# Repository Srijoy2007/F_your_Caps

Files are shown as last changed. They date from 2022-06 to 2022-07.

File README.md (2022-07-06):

Bobby-Pad is a 9 switches budget macro-keyboard with a great quality...

#PROJECT DETAILS ->
    1. PCB :- the pcb is based of RP2040 , the pcb has the basic structure of any RP2040 PCB 
              it contains a USB C recptable support , Along with it it contains a Rotary Encoder 
	      switch and a 2.3cm OLED. 
    2. FIRMWARE :- Since RP2040 doesen't support QMK so I am builduing a custom FIRMWARE with Rust(will update it soon)
    3. CASE & PLATE :- For the Case and plate I am planning for alimunium to give it a weight , the design still under process

# ROAD MAP ->
  
  -> First commit the V1 with STM32 [ 05/22] { STM32 doesnt fit into the budget}
  -> Second change V2 with RP2040 [06/22] {Had issue with position and connections}
  -> Third change V3 with RP2040 [06/22]  { 0 errors }

#My thoughts ->
 * I built the Version 1 without knowing much about its price but when I knew that I was shocked so I switched to RP2040 which was not 
   that difficult to adapt as it has a good datasheet and guide provided in its official website , but this mcu is not much supported by 
   the keyboard community still I feel comfortable to use this one . I ordered a Raberry Pi PICO for dry run and testing the firmware code 
   before putting it to the PCBs (Might upload pics of it). 

#BUDGET -> 
 
 * PCB build + Bottom Assembly : 44$ FOR 5 PCB (i.e. Rs. 3,432) 
 * SWITCHES (Cherry MX RGB blue) : 26$ FOR 50 switches (i.e. Rs.2,025)
 * Rotary encoder + oled :  8$ - 9$  per keeb :- total 40$ - 45$ for 5 keeb
 * Case & plate : --

  #CURRENT TOTAL FOR EACH KEYBOARD (NO PLATE &  CASE) : 24$ build cost 
#TO-DO ->
 [X] PCB design
 [x] PCB Test
 [ ] Firmware test/build 
 [ ] Case and plate design 
 [ ] Final test

* All the pcb related files are uploaded

© 2022 GitHub, Inc.
Terms
Privacy
Security
Status
Docs
Contact GitHub
Pricing
API
Training
Blog
About

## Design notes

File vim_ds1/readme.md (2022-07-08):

# vim_ds1

vim_ds1

*A short description of the keyboard/project*

* Keyboard Maintainer: [Srijoy Ganguly](https://github.com/Srijoy2007)
* Hardware Supported: *The PCBs, controllers supported*
* Hardware Availability: *Links to where you can find this hardware*

Make example for this keyboard (after setting up your build environment):

   make vim_ds1:default 

Flashing example for this keyboard:

    make vim_ds1:default:flash

See the [build environment setup](https://docs.qmk.fm/#/getting_started_build_tools) and the [make instructions](https://docs.qmk.fm/#/getting_started_make_guide) for more information. Brand new to QMK? Start with our [Complete Newbs Guide](https://docs.qmk.fm/#/newbs).

## Bootloader

Enter the bootloader in 3 ways:

* **Bootmagic reset**: Hold down the key at (0,0) in the matrix (usually the top left key or Escape) and plug in the keyboard
* **Physical reset button**: Briefly press the button on the back of the PCB - some may have pads you must short instead
* **Keycode in layout**: Press the key mapped to `RESET` if it is available

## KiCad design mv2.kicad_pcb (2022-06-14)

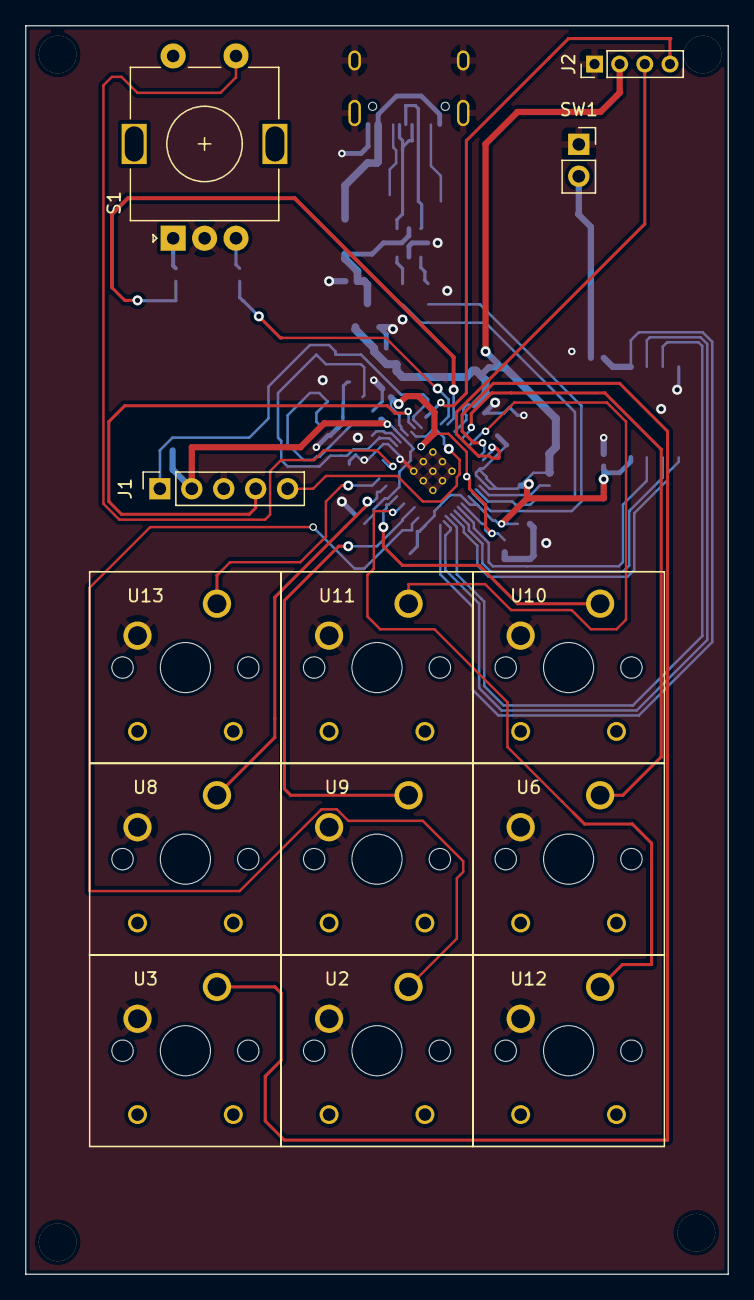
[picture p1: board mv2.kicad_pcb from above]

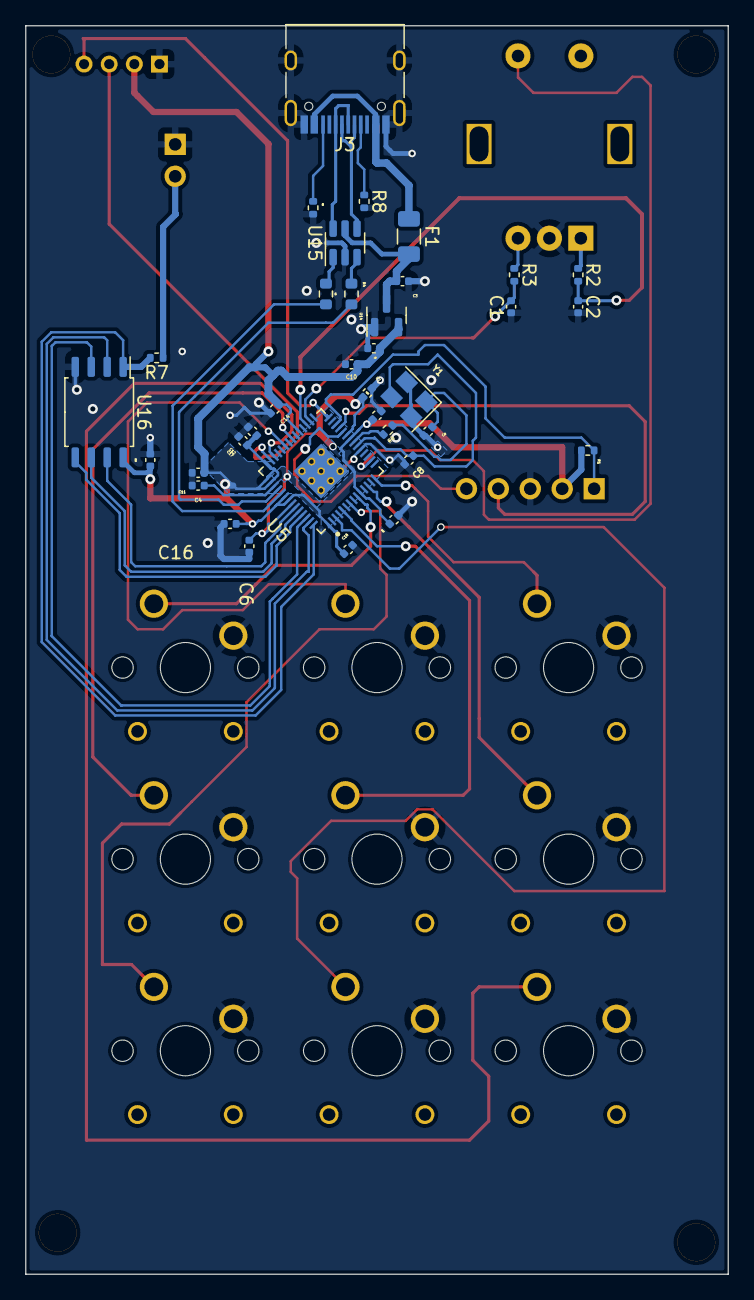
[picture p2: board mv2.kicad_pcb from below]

Board: 2 copper layers, 55.9 x 99.3 mm, 48 parts (35 on the bottom side), 42 nets.

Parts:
C1, C2, C6, C7, C12, C13, C14, C15, C16, C17, C18, C19: 100nF; C_0402_1005Metric
C3, C4, C5, C11: 1uF; C_0402_1005Metric
C8: 22pF; C_0402_1005Metric
C10: 10uF; C_0402_1005Metric
Ce: 22pF; C_0402_1005Metric
F1: 500mA; Fuse_1206_3216Metric
J1: SWD; PinSocket_1x05_P2.54mm_Vertical
J2: Conn_01x04; PinHeader_1x04_P2.00mm_Vertical
J3: USB_C_Receptacle_USB2.0; USB_C_Receptacle_HRO_TYPE-C-31-M-12
R1, R6, R7: 1k; R_0402_1005Metric
R2, R3: 27k; R_0402_1005Metric
R4, R5: 27R; R_0603_1608Metric
R8, R9: 5k1; R_0402_1005Metric
S1: ENCODER-SWITCH; RotaryEncoder_Alps_EC11E-Switch_Vertical_H20mm
SW1: SW_Push; PinSocket_1x02_P2.54mm_Vertical
U2, U3, U6, U8, U9, U10, U11, U12, U13: MX1A-11NN; CHERRY_MX1A-11NN_SWITCH
U5: RP2040; QFN40P700X700X90-57N
U14: XC6206PxxxMR-Regulator_Linear; SOT-23
U15: USBLC6-2SC6; SOT-23-6
U16: W25Q128JVS; SOIC-8_5.23x5.23mm_P1.27mm
Y1: 12MHz; Crystal_SMD_3225-4Pin_3.2x2.5mm

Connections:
+1V1: C4.1, C6.1, C7.1, U5.23 (DVDD), U5.45 (VREG_VOUT), U5.50 (DVDD)
+3V3: C5.2, C10.1, C11.1, C12.1, C13.1, C14.1, C15.1, C16.1, C17.1, C18.1, C19.1, J1.2, J2.2, R1.1, U5.1 (IOVDD), U5.10 (IOVDD), U5.22 (IOVDD), U5.33 (IOVDD), U5.42 (IOVDD), U5.43 (ADC_AVDD), U5.44 (VREG_VIN), U5.48 (USB_VDD), U5.49 (IOVDD), U14.2 (VO), U16.8 (VCC)
+5V: C3.2, F1.2, U14.3 (VI), U15.5 (VBUS)
/But_1: U2.P$1, U5.3 (GPIO1)
/But_2: U5.5 (GPIO3), U9.P$1
/But_3: U5.7 (GPIO5), U12.P$1
/But_4: U3.P$1, U5.40 (GPIO28/ADC2)
/But_6: U5.9 (GPIO7), U10.P$1
/But_8: U5.12 (GPIO9), U8.P$1
/But_9: U5.14 (GPIO11), U13.P$1
/But_11: U5.35 (GPIO23), U6.P$1
/But_12: U5.37 (GPIO25), U11.P$1
/CC2: J3.B5 (CC2), R9.1
/GPIO19: C1.2, R3.2, U5.30 (GPIO19)
/GPIO20: C2.1, R2.2, U5.31 (GPIO20)
/XTAL_O: Ce.2, R6.1, Y1.1
/~USB_BOOT: R7.1, SW1.2
CS: R7.2, U5.56 (QSPI_CSN), U16.1 (~CS)
D_N: R4.1, U15.3 (I/O2)
D_P: R5.1, U15.1 (I/O1)
D_USB_N: J3.A7 (D-), J3.B7 (D-), U15.4 (I/O2)
D_USB_P: J3.A6 (D+), J3.B6 (D+), U15.6 (I/O1)
GND: C1.1, C2.2, C3.1, C4.2, C5.1, C6.2, C7.2, C8.1, C10.2, C11.2, C12.2, C13.2, C14.2, C15.2, C16.2, C17.2, C18.2, C19.2, Ce.1, J1.3, J2.1, J3.A1 (GND), J3.A12 (GND), J3.B1 (GND), J3.B12 (GND), J3.S1 (SHIELD), R8.2, R9.2, S1.C, SW1.1, U2.P$2, U3.P$2, U5.19 (TESTEN), U5.57 (GND), U6.P$2, U8.P$2, U9.P$2, U10.P$2, U11.P$2, U12.P$2, U13.P$2, U14.1 (GND), U15.2 (GND), U16.4 (GND), Y1.2, Y1.4
GPI0 17: J2.4, U5.28 (GPIO17)
GPIO21: S1.S1, U5.16 (GPIO13)
GPIO 18: J2.3, U5.41 (GPIO29/ADC3)
unnamed: J3.A5 (CC1), R8.1
unnamed: R2.1, S1.A
unnamed: R3.1, S1.B
unnamed: R4.2, U5.46 (USB_DM)
unnamed: R5.2, U5.47 (USB_DP)
QSPI_CLK: U5.52 (QSPI_SCLK), U16.6 (CLK)
SD0: U5.53 (QSPI_SD0), U16.5 (DI(IO0))
SD1: U5.55 (QSPI_SD1), U16.2 (DO(IO1))
SD2: U5.54 (QSPI_SD2), U16.3 (IO2)
SD3: U5.51 (QSPI_SD3), U16.7 (IO3)
SWCLK: J1.5, U5.24 (SWCLK)
SWD: J1.4, U5.25 (SWD)
VBUS: F1.1, J3.A4 (VBUS), J3.A9 (VBUS), J3.B4 (VBUS), J3.B9 (VBUS)
XTAL_IN: C8.2, U5.20 (XIN), Y1.3
XTAL_OUT: R6.2, U5.21 (XOUT)
~RESET: J1.1, R1.2, U5.26 (RUN)

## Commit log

2022-06-02 Add files via upload
    New , pcb and schematic with the RP2040 micro - controller
    [PCB.kicad_pcb, mv2.kicad_sch]
2022-06-06 pcb routed
    [PCB.kicad_pcb, mv2.kicad_pcb, mv2.kicad_sch]
2022-06-10 Add files via upload
    A 9 key dev tool made with rp2040 version 3
    (prototype)
    [Kailh Polia.step, MV3.kicad_sch, PCB.kicad_pcb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]
2022-06-14 Version 3 final version of the pcb
    [mv2.kicad_pcb, mv2.kicad_sch]
